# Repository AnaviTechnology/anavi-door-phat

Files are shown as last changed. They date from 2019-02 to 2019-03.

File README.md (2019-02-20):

# Anavi Door pHAT

Anavi Door pHAT is an open source hardware Raspberry Pi pHAT (add-on board) for detecting if door is opened or closed. The board has been designed entirely with free and open source software. It features:

* Slots for up to 3 door sensors
* Piezoelectric buzzer
* Slot for PIR motion sensor
* Slots for up to 3 plug and play I2C sensors for temperature, barometric pressure, humidity and light
* UART (Universal asynchronous receiver/transmitter) pins for debugging
* EEPROM

# Dependencies

Uses PKM13EPYH4000-A0 footprint from https://github.com/nosuz/kicad-lib

# License

The project is released under the [Creative Commons Attribution-ShareAlike 4.0 International (CC BY-SA 4.0)](https://creativecommons.org/licenses/by-sa/4.0/).

Note: This is a human-readable summary of (and not a substitute for) the [license](https://creativecommons.org/licenses/by-sa/4.0/legalcode).

You are free to:

Share — copy and redistribute the material in any medium or format Adapt — remix, transform, and build upon the material for any purpose, even commercially. The licensor cannot revoke these freedoms as long as you follow the license terms. Under the following terms:

Attribution — You must give appropriate credit, provide a link to the license, and indicate if changes were made. You may do so in any reasonable manner, but not in any way that suggests the licensor endorses you or your use. ShareAlike — If you remix, transform, or build upon the material, you must distribute your contributions under the same license as the original. No additional restrictions — You may not apply legal terms or technological measures that legally restrict others from doing anything the license permits. Notices:

You do not have to comply with the license for elements of the material in the public domain or where your use is permitted by an applicable exception or limitation. No warranties are given. The license may not give you all of the permissions necessary for your intended use. For example, other rights such as publicity, privacy, or moral rights may limit how you use the material.

You will have to provide a link to the original creator of the project http://www.anavi.technology on any documentation or website.

Credit can be attributed through a link to the creator website: http://www.anavi.technology

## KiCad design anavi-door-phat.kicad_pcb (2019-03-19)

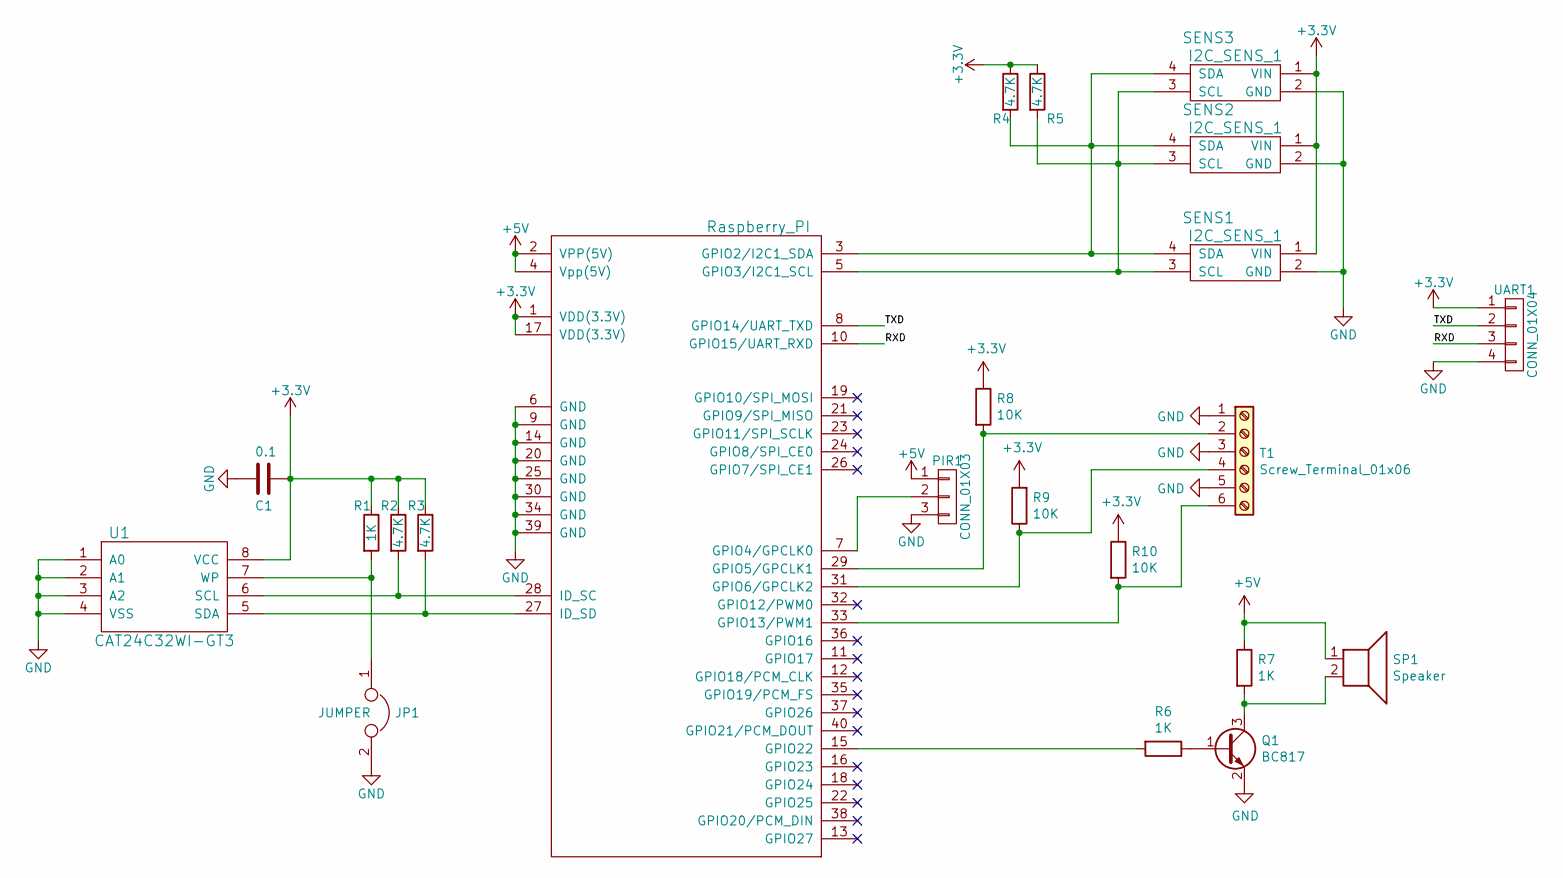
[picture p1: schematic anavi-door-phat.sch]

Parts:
C1: 0.1; C_0603_HandSoldering
JP1: JUMPER; Pin_Header_Straight_1x02
PIR1: CONN_01X03; Pin_Header_Straight_1x03
Q1: BC817; SOT-23
R1, R6, R7: 1K; R_0603_1608Metric
R2, R3, R4, R5: 4.7K; R_0603_1608Metric
R8, R9, R10: 10K; R_0603_1608Metric
RASP_CONN1: Raspberry_PI; Pin_Header_Straight_2x20
SENS1, SENS2, SENS3: I2C_SENS_1; Pin_Header_Straight_1x04
SP1: Speaker; PKM13EPYH4000-A0
T1: Screw_Terminal_01x06; TerminalBlock_Phoenix_MKDS-1,5-6_1x06_P5.00mm_Horizontal
U1: CAT24C32WI-GT3; DIP-8_W7.62mm
UART1: CONN_01X04; Pin_Header_Straight_1x04

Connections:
+3V3: C1.1, R1.1, R2.1, R3.1, R4.1, R5.1, R8.1, R9.2, R10.1, RASP_CONN1.1 (VDD(3.3V)), RASP_CONN1.17 (VDD(3.3V)), SENS1.1 (VIN), SENS2.1 (VIN), SENS3.1 (VIN), U1.8 (VCC), UART1.1; also elsewhere on the board
+5V: PIR1.1, R7.1, RASP_CONN1.2 (VPP(5V)), RASP_CONN1.4 (Vpp(5V)), SP1.1; also elsewhere on the board
/RXD: RASP_CONN1.10 (GPIO15/UART_RXD), UART1.3; also elsewhere on the board
/TXD: RASP_CONN1.8 (GPIO14/UART_TXD), UART1.2; also elsewhere on the board
GND: C1.2, JP1.2, PIR1.3, Q1.2 (E), RASP_CONN1.6 (GND), RASP_CONN1.9 (GND), RASP_CONN1.14 (GND), RASP_CONN1.20 (GND), RASP_CONN1.25 (GND), RASP_CONN1.30 (GND), RASP_CONN1.34 (GND), RASP_CONN1.39 (GND), SENS1.2 (GND), SENS2.2 (GND), SENS3.2 (GND), T1.1, T1.3, T1.5, U1.1 (A0), U1.2 (A1), U1.3 (A2), U1.4 (VSS), UART1.4; also elsewhere on the board
unnamed: JP1.1, R1.2, U1.7 (WP)
unnamed 6: PIR1.2, RASP_CONN1.7 (GPIO4/GPCLK0); also elsewhere on the board
unnamed: Q1.1 (B), R6.1
unnamed: Q1.3 (C), R7.2, SP1.2
unnamed: R2.2, RASP_CONN1.28 (ID_SC), U1.6 (SCL)
unnamed: R3.2, RASP_CONN1.27 (ID_SD), U1.5 (SDA)
unnamed: R4.2, RASP_CONN1.3 (GPIO2/I2C1_SDA), SENS1.4 (SDA), SENS2.4 (SDA), SENS3.4 (SDA)
unnamed: R5.2, RASP_CONN1.5 (GPIO3/I2C1_SCL), SENS1.3 (SCL), SENS2.3 (SCL), SENS3.3 (SCL)
unnamed: R6.2, RASP_CONN1.15 (GPIO22)
unnamed: R8.2, RASP_CONN1.29 (GPIO5/GPCLK1), T1.2
unnamed: R9.1, RASP_CONN1.31 (GPIO6/GPCLK2), T1.4
unnamed: R10.2, RASP_CONN1.33 (GPIO13/PWM1), T1.6

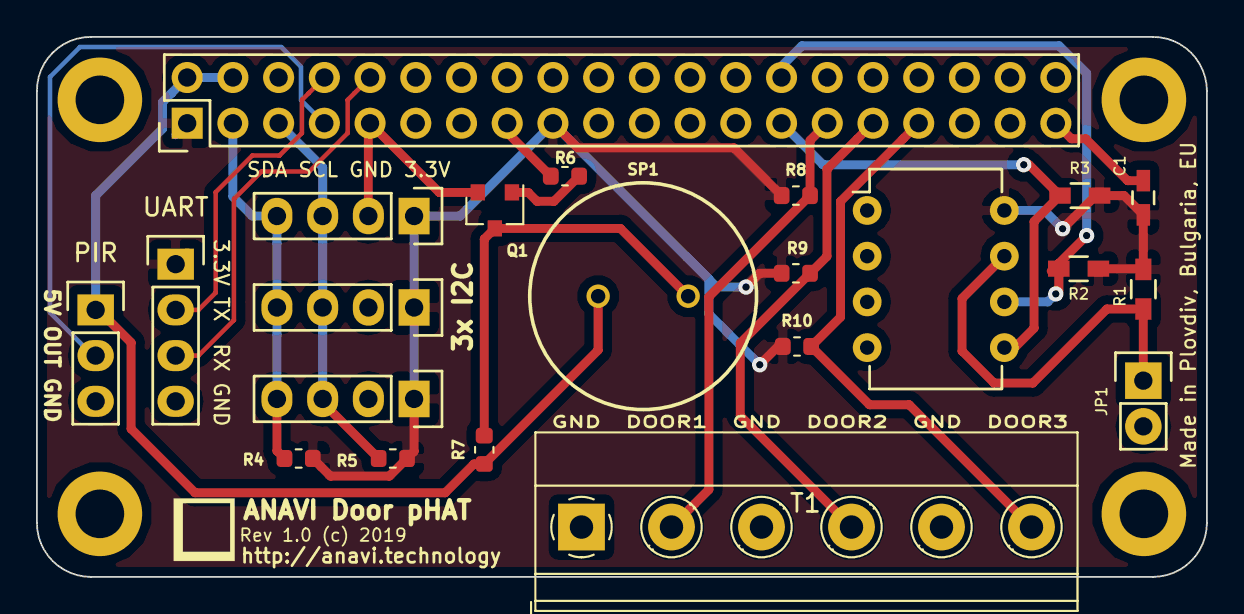
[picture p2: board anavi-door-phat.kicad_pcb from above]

Board: 2 copper layers, 65.0 x 30.0 mm, 26 parts (0 on the bottom side), 17 nets.

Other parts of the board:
PIR: CONN_01X03; Pin_Header_Straight_1x03
REF1, REF2, REF3, REF4: MountingHole_2.7mm_M2.5_DIN965_Pad
UART: CONN_01X04; Pin_Header_Straight_1x04

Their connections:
+3V3: UART.1; also elsewhere on the board
+5V: PIR.1; also elsewhere on the board
/RXD: UART.3; also elsewhere on the board
/TXD: UART.2; also elsewhere on the board
GND: PIR.3, UART.4; also elsewhere on the board
unnamed 6: PIR.2; also elsewhere on the board

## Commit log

2019-02-20 anavi-door-phat: Initial release
    KiCad project for the open source hardware ANAVI Door pHAT.
    [anavi-door-phat-2019-02-20-16-55-52.sch, anavi-door-phat.kicad_pcb, anavi-door-phat.sch]
2019-02-20 anavi-door-phat.kicad_pcb: Fix silkscreen
    Improve positions of the text on the silkscreen layer.
    [anavi-door-phat.kicad_pcb]
2019-03-19 anavi-door-phat.kicad_pcb: Assembly instructions
    Add notes for assembly on the F.Fab layer.
    [anavi-door-phat.kicad_pcb]

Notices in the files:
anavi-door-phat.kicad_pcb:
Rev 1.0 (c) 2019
